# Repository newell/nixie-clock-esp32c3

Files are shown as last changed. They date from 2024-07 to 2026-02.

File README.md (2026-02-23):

# Nixie Clock ESP32-C3  

## Features:

- **CAD 3D Model of Case and Components using [build123d](https://github.com/gumyr/build123d)**
- **Six IN-12A Nixie Tubes and Four Colon Indicators**
- **ESP32-C3 microcontroller**
- **Powered via USB-C**
- **[High Voltage Flyback Converter](https://github.com/newell/hv-flyback-converter)**
- **WiFi Provisioning via Bluetooth**
- **Sound**
- **Motion Sensing for Sleep Mode**
- **Webserver and Client to Control Settings**:
  - WiFi Credentials
  - 12-hour or 24-hour format
  - NTP server
  - Colon Indicators (Blinking, Always On, Off)
  - Color of LEDs (Spectrum Cycle or Static Mode)
  - Timezone













https://github.com/user-attachments/assets/77bc2790-672e-41c1-a4d4-c8e7e0b7ab1b

https://github.com/user-attachments/assets/c225c358-999a-4b4a-92b9-9c901be83272

 ### TODO
- [x] Hourly Slot Machine Effect
- [x] LED Spectrum Cycle
- [ ] Motion Sleep Mode
- [ ] Colon Indicator (currently only blinking supported)

## CAD Model of Clock Case

To design the clock case I used [build123d](https://github.com/gumyr/build123d) (you can [read the docs here](https://build123d.readthedocs.io/en/latest/)).  

build123d1

build123d2

build123d3

## Clock Control Interface

This project contains a web-based interface to control settings for the clock. The interface is served by the ESP32-C3 and can be accessed at [esp-home.local](http://esp-home.local).

### Features

- **Real-Time Control**: Adjust clock settings in real-time using WebSockets.
- **User-Friendly Interface**: A clean and responsive web interface built with HTML, CSS, and JavaScript.
- **Customizable Settings**: Change various clock settings like time, timezone, 24 or 12 hour format, display color and brightness, and more.

[ClockControlInterface.webm](https://github.com/user-attachments/assets/71b5c2da-ff7b-42fa-be0a-e68aa2519f6b)

## Design

This section contains some behind the scenes of the various stages of designing the clock, including prototyping, debugging, and iterative improvements. 

### Handsoldered PCB Testing and Debugging

- [x] Display current time synced with NTP
- [x] LEDs
- [x] Sound







### PCBs

Black PCBs arrived from JLCPCB:

clock-pcbs

### Kicad 3D Model

clock

clock-back

### Single Tube

Before receiving my ESP32-C3 development board, I tested the ability to toggle numbers on a Nixie tube and verified the functionality of my homemade high voltage power supply. I created a boost converter using the toner transfer method. This DC-DC converter takes a +12VDC input and outputs approximately +170VDC. I used an Arduino Due board to cycle through the numbers on the Nixie tube.

https://github.com/user-attachments/assets/79ee931c-0b5a-45fc-ba34-53a26bd78811

### Six Tubes Toggling

Upon receiving my ESP32-C3-DevKitM-1 development board, I wired up all six Nixie tubes on a breadboard using K155ID1 1601 DIP16 chips to drive the tubes. On the final PCB, I used SMT transistors to drive each pin of the tubes individually through shift registers.

https://github.com/user-attachments/assets/ffbe7d87-d1e9-45e2-91e5-0040cae557c9

### Six Tubes NTP Time and Sound

Next, I wrote code for the ESP32-C3 to update its time via NTP and drive the tubes accordingly (details are in the code). Additionally, I successfully integrated sound using codecs and a power amplifier.

https://github.com/user-attachments/assets/b822d686-eec8-4e32-874c-11a30fe7fb55

### LEDs

Added code to have the ESP32-C3 drive some LEDs.  There are LEDs underneath each tube on the clock.

https://github.com/user-attachments/assets/37ba964b-dcfa-438d-87e9-e53fea1e2fda

## License

This project is dual-licensed to address both software and hardware components:

- **Software**: The software in this project, other than iro.js, is licensed under the MIT License. You can use, copy, modify, merge, publish, distribute, sublicense, and/or sell copies of the software, provided that the original copyright notice and this permission notice are included in all copies or substantial portions of the software. For more details, see the [LICENSE](./LICENSE) file.

- **iro.js**: Mozilla Public License 2.0 (https://github.com/jaames/iro.js)

- **Hardware**: The hardware schematics and designs in this project are licensed under the CERN Open Hardware License (CERN OHL). You are free to use, modify, and distribute the hardware designs, provided that any modifications are also shared under the same license. For more details, see the [CERN OHL License](./CERN_OHL_LICENSE) file.

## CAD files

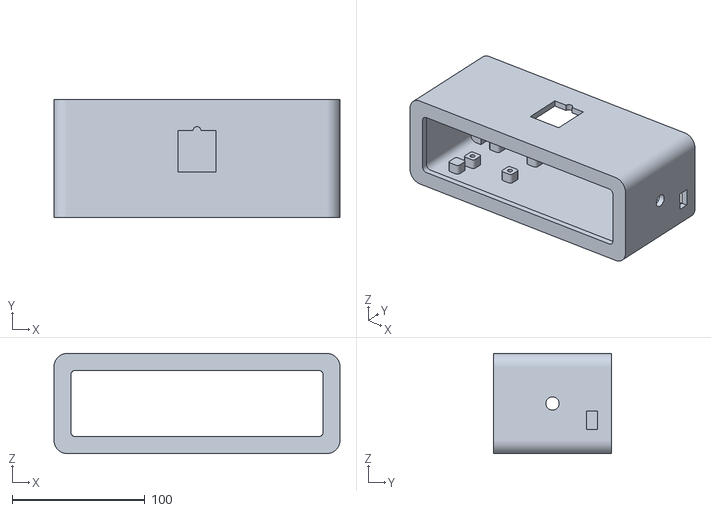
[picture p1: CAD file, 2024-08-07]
case/enclosure.stl
215.4 x 88.9 x 75.4

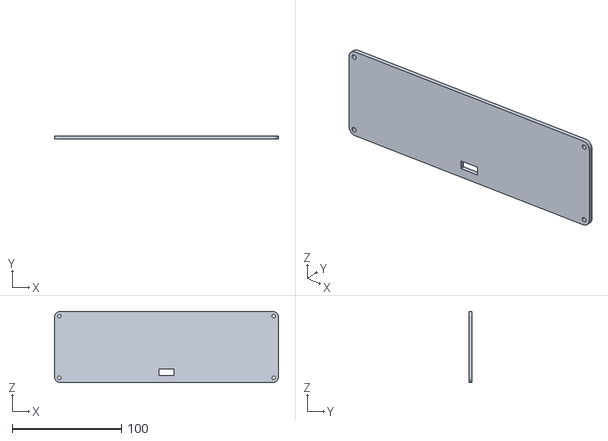
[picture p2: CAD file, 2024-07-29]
case/rear_panel.stl
205.1 x 3.00 x 65.1

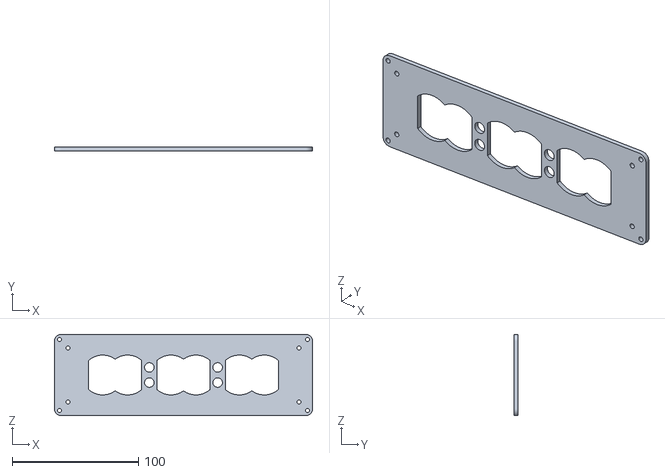
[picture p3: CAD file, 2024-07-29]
case/front_panel.stl
204.3 x 3.00 x 64.3

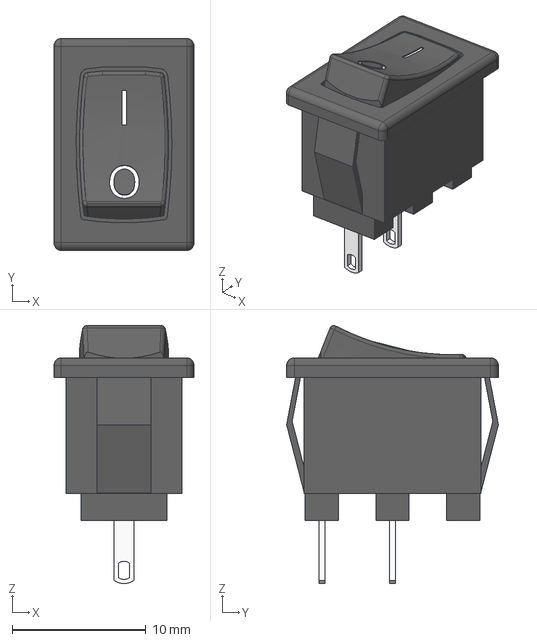
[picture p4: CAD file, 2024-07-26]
case/KCD11.step
10.5 x 15.8 x 19.3 mm

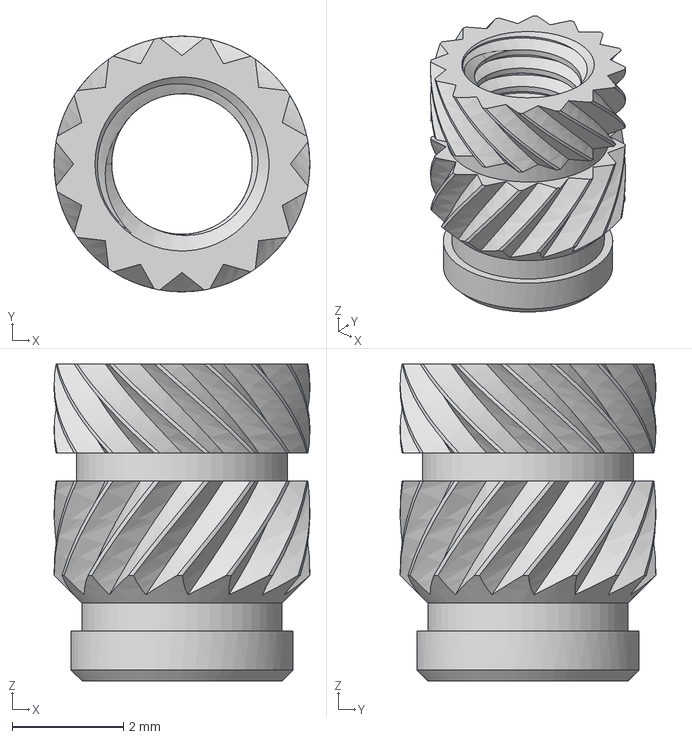
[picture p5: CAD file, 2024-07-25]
case/M3_Standard.step
4.60 x 4.60 x 5.70 mm

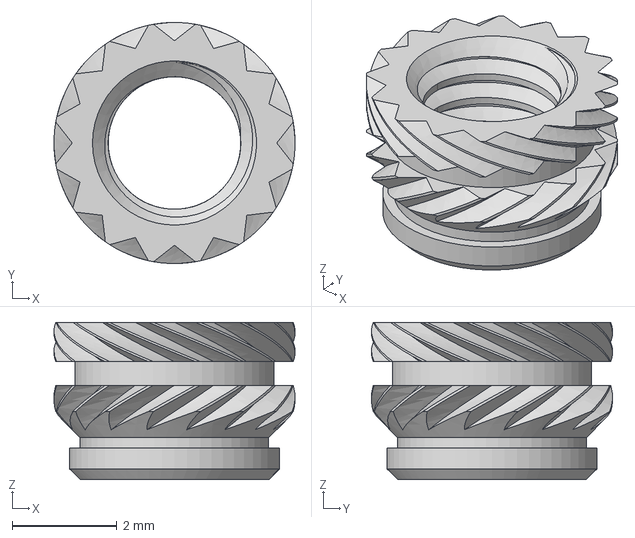
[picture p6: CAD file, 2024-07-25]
case/M3_Short.step
4.60 x 4.60 x 3.00 mm

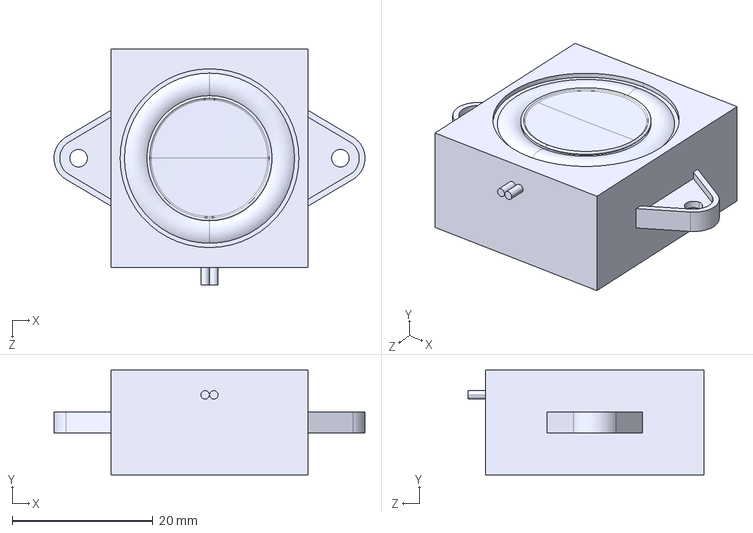
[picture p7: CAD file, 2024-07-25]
case/Speaker.STEP
44.2 x 14.8 x 33.5 mm

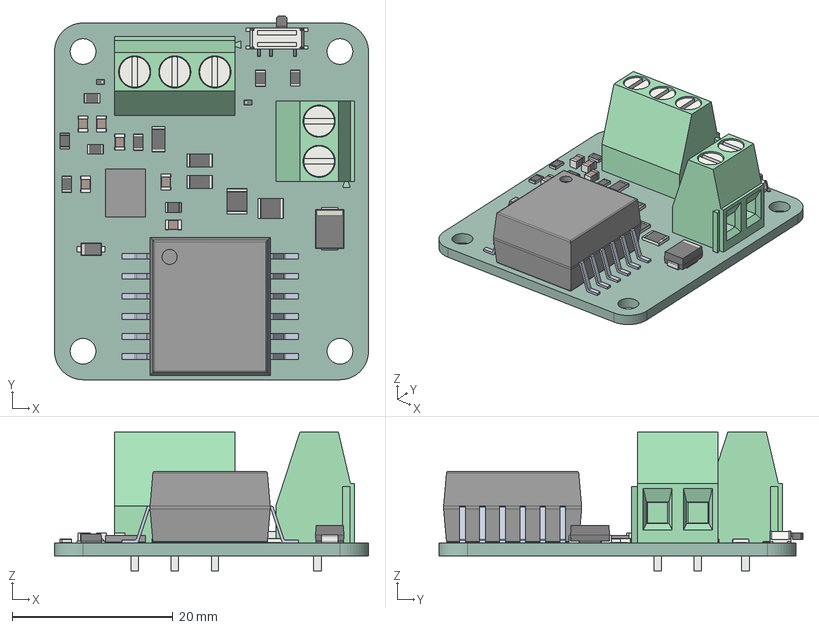
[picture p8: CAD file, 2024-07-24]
case/converter.step
39.1 x 45.3 x 17.3 mm
R_1206_3216Metric x 3
C_0805_2012Metric x 6
TerminalBlock_Phoenix_MKDS_15_2_1x02_P500mm_Horizontal
ASSEMBLY x 2
R_0805_2012Metric x 8
D_SOD-882 x 2
D_SMB
D_SOD_123F
Fusion_sp
TerminalBlock_Phoenix_MKDS_15_3_1x03_P500mm_Horizontal
R_1210_3225Metric x 2
converter_PCB

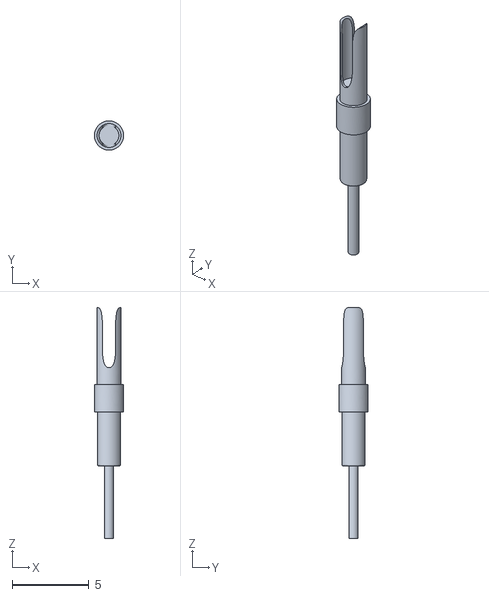
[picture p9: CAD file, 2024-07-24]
case/SocketPin.stl
1.90 x 1.90 x 15.0

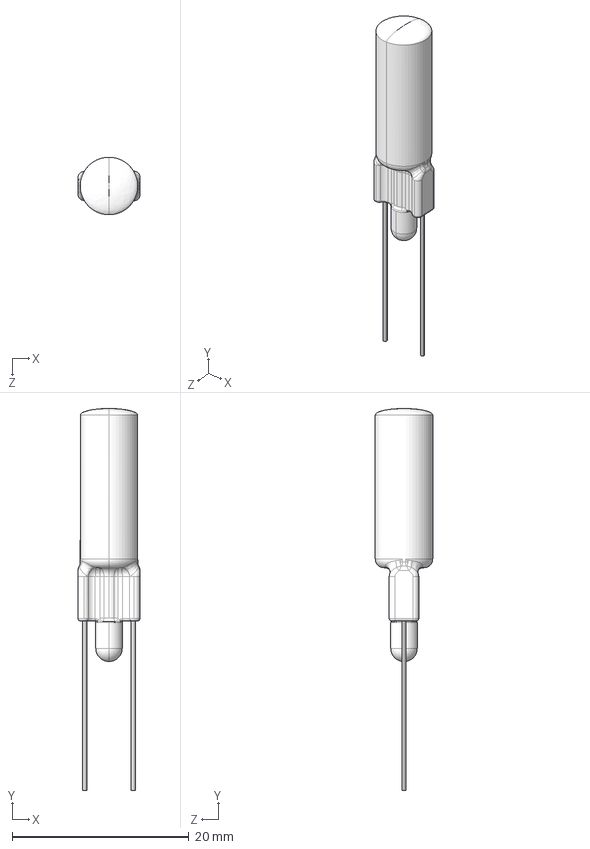
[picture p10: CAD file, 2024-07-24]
case/INS1.STEP
7.00 x 43.2 x 6.50 mm
INS1-Glaskörper_01
INS1_Inlay_01

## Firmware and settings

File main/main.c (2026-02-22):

#include <driver/gpio.h>
#include <esp_log.h>
#include <esp_netif.h>
#include <nvs_flash.h>
#include <string.h>
#include <time.h>

#include "audio.h"
#include "clock.h"
#include "config.h"
#include "leds.h"
#include "sntp.h"
#include "vfs.h"
#include "wifi_prov.h"
#include "ws_server.h"

#define HVEN GPIO_NUM_7
static const char* TAG = "main";

TaskHandle_t led_slot_machine_task_handle = NULL;
TaskHandle_t play_audio_task_handle = NULL;
TaskHandle_t led_mode_task_handle = NULL;

void led_slot_machine_task(void* pvParameters) {
    while (1) {
        ulTaskNotifyTake(pdTRUE, portMAX_DELAY);
        ESP_LOGI(TAG, "LED Slot Triggered");
        led_send_msg(LED_CMD_SLOT_MODE, 0, 0, 0);
    }
}

void play_audio_task(void* pvParameters) {
    while (1) {
        ulTaskNotifyTake(pdTRUE, portMAX_DELAY);
        ESP_LOGI(TAG, "Playing Hourly Audio");
        audio_handle_info(SOUND_TYPE_GOOD_FOOT);
    }
}

void hourly_task(void* pvParameters) {
    while (1) {
        time_t now;
        struct tm timeinfo;

        time(&now);
        localtime_r(&now, &timeinfo);

        int seconds_until_next_hour =
            (60 - timeinfo.tm_min) * 60 - timeinfo.tm_sec;
        if (seconds_until_next_hour <= 0) seconds_until_next_hour = 3600;
        vTaskDelay(pdMS_TO_TICKS(seconds_until_next_hour * 1000));
        ESP_LOGI(TAG, "Hour changed!");

        // /* DEBUG: Trigger every minute */
        // int seconds_until_next_minute = 60 - timeinfo.tm_sec;
        // if (seconds_until_next_minute <= 0) seconds_until_next_minute = 60;

        // vTaskDelay(pdMS_TO_TICKS(seconds_until_next_minute * 1000));

        clock_send_slot_machine_with_leds();
    }
}

void app_main(void) {
    esp_err_t ret = nvs_flash_init();
    if (ret == ESP_ERR_NVS_NO_FREE_PAGES ||
        ret == ESP_ERR_NVS_NEW_VERSION_FOUND) {
        ESP_ERROR_CHECK(nvs_flash_erase());
        ESP_ERROR_CHECK(nvs_flash_init());
    }

    ESP_ERROR_CHECK(esp_event_loop_create_default());
    ESP_ERROR_CHECK(vfs_init());
    ESP_ERROR_CHECK(esp_netif_init());

    config_init();

    // Sync LED mode from config to RAM
    char saved_mode[16] = {0};
    read_config_value("led_mode", saved_mode, sizeof(saved_mode));

    if (strlen(saved_mode) > 0) {
        led_set_ram_mode(saved_mode);
    } else {
        led_set_ram_mode("static");
    }

    wifi_prov_init();
    sync_sntp();

    configure_leds();
    clock_init();  // IMPORTANT: Initialize clock BEFORE hourly task

    // High Voltage Enable
    gpio_config_t io_conf = {.intr_type = GPIO_INTR_DISABLE,
                             .mode = GPIO_MODE_OUTPUT,
                             .pin_bit_mask = (1ULL << HVEN),
                             .pull_down_en = 0,
                             .pull_up_en = 0};
    gpio_config(&io_conf);
    gpio_set_level(HVEN, 1);

    ESP_ERROR_CHECK(start_webserver());
    ESP_ERROR_CHECK(audio_play_start());

    // Create Tasks
    xTaskCreate(led_task, "LED Master", 4096, NULL, 5, NULL);
    xTaskCreate(led_mode_task, "LED Mode", 2048, NULL, 2,
                &led_mode_task_handle);
    xTaskCreate(led_slot_machine_task, "Slot Trigger", 2048, NULL, 3,
                &led_slot_machine_task_handle);
    xTaskCreate(play_audio_task, "Play Audio", 4096, NULL, 4,
                &play_audio_task_handle);
    xTaskCreate(hourly_task, "Hourly", 2048, NULL, 1, NULL);

    ESP_LOGI(TAG, "System initialization complete");
}

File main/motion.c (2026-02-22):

#include "motion.h"

#include <driver/gpio.h>
#include <esp_log.h>
#include <esp_timer.h>
#include <freertos/FreeRTOS.h>
#include <freertos/queue.h>
#include <freertos/task.h>

uint32_t counter = 0;

uint32_t last_interrupt_time = 0;

static const char* TAG = "motion sensor";

static QueueHandle_t gpio_evt_queue = NULL;

static void IRAM_ATTR gpio_isr_handler(void* arg) {
    uint32_t current_time =
        esp_timer_get_time() / 1000;  // Get time in milliseconds

    if ((current_time - last_interrupt_time) > DEBOUNCE_DELAY_MS) {
        last_interrupt_time = current_time;
        uint32_t gpio_num = (uint32_t)arg;
        xQueueSendFromISR(gpio_evt_queue, &gpio_num, NULL);
        counter = 0;
    }
}

void timer_callback(void* arg) {
    // Increment counter every second
    counter++;
}

void sleep_task(void* pvParameter) {
    while (1) {
        // Check if counter reaches half hour (1800 seconds)
        if (counter >= 1800) {
            printf("Yo dawg...TODO\n");
            // TODO - This is where you would put the clock to sleep
        }
        vTaskDelay(1000 / portTICK_PERIOD_MS);  // Check every second
    }
}

static void gpio_task(void* arg) {
    uint32_t io_num;
    for (;;) {
        if (xQueueReceive(gpio_evt_queue, &io_num, portMAX_DELAY)) {
            ESP_LOGI(TAG, "Motion detected on GPIO %u", (unsigned int)io_num);
        }
    }
}

void motion_init(void) {
    // Start motion sensor
    gpio_config_t io_conf;
    io_conf.intr_type = GPIO_INTR_POSEDGE;
    io_conf.mode = GPIO_MODE_INPUT;
    io_conf.pull_down_en = true;
    // io_conf.pull_up_en = false;
    io_conf.pin_bit_mask = (1ULL << GPIO_MOTION_INTR_PIN);
    gpio_config(&io_conf);

    // create a queue to handle gpio event from isr
    gpio_evt_queue = xQueueCreate(10, sizeof(uint32_t));

    // //start gpio task
    xTaskCreate(gpio_task, "gpio_task", 2048, NULL, 10, NULL);

    // install gpio isr service
    gpio_install_isr_service(0);
    // hook isr handler for specific gpio pin
    gpio_isr_handler_add(GPIO_MOTION_INTR_PIN, gpio_isr_handler,
                         (void*)GPIO_MOTION_INTR_PIN);

    // printf("Minimum free heap size: %"PRIu32" bytes\n",
    // esp_get_minimum_free_heap_size());

    // Create and start timer
    esp_timer_handle_t timer;
    esp_timer_create_args_t timer_args = {.callback = &timer_callback,
                                          .name = "periodic_timer"};
    esp_timer_create(&timer_args, &timer);
    esp_timer_start_periodic(
        timer, TIMER_INTERVAL * 1000);  // Timer interval in microseconds

    // Create task to monitor counter
    xTaskCreate(&sleep_task, "sleep_task", 4096, NULL, 5, NULL);
}

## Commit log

2024-07-15 Add code and schematics
    [clock.kicad_sch, drivers_1.kicad_sch, drivers_2.kicad_sch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]
2024-07-21 Update led strip to take 6 leds on the pcb. Update the clock logic to deal with the shift register layout on the pcb.
2024-07-23 Initial build123d case file
2024-07-24 Add Step files for nixie tubes, indicators and socket pins
    [INS1.STEP, SocketPin.stl]
2024-07-24 Add step files for the pcbs
    [converter.step]
2024-07-25 Add mode CAD models for the case
    [M3_Short.step, M3_Standard.step, Speaker.STEP]
2024-07-25 Update case
2024-07-26 Add CAD file for rocker switch
    [KCD11.step]
2024-07-26 Add STL files for 3D prints
    [enclosure.stl, front_panel.stl, rear_panel.stl]
2024-07-29 Add updates of case output files
    [enclosure.stl, front_panel.dxf, front_panel.stl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]
2024-08-07 Remove DXF file, update enclosure, and widen motion sensor holes a bit.
    [enclosure.stl, front_panel.dxf]
2024-08-07 Add Gerbers and drill files
    [clock-B_Cu.gbr, clock-B_Mask.gbr, clock-B_Paste.gbr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]
2024-08-13 Add LED power up sequence
2024-08-14 Save provisioning credentials to config in callback. Add hourly led and sound tasks, on the hour.
2024-09-03 Update LED code to restore configuration color after party lights
2024-09-16 Add slot machine effect to the hourly task
2024-10-01 Add High Voltage enable.
2026-02-22 Add queueing service for LEDs and Nixie tubes. Add spectrum cycle logic for LEDs.
2026-02-26 Update CAD for case

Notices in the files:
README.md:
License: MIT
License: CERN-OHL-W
